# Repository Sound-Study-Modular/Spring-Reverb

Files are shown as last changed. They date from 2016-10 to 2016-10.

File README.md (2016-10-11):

# Spring-Reverb

The Spring Reverb is a flexible, easy-to-build voltage controlled DIY mono spring reverb module. Traditional guitar reverbs are tuned to the sound of the guitar and the amplifier it is played through. This circuit is different; designed to be relatively clean and high-fi, with a lot of bass response. It can also be abused and driven into (externally patched) feedback.

The circuit, plans and PCB/panel designs are open source and shared under Creative Commons.

- Works with a variety of spring reverb tanks, or with the Accutronics BTDR-2 reverb ‘brick’ designed by Brian Neunaber
- Includes PCB panel designs that can be very cheaply produced.
- Vactrol crossfade between dry and wet
- Tilt EQ on the reverb send to tune the voice of the reverb
- X-Fade input so the module can also be used as a standalone vactrol crossfader
- Attenuverter on the crossfade CV input
- Options for reverb tank connection and placement including front panel sockets.
- Optional (unbuffered) PCB connections for 100% wet and post-EQ dry outputs
- 6hp wide (NB: If using the brick, mounted horizontally, the brick extends 5mm over the PCB to the left of the module, around 25mm back from the front panel, so mount the reverb next to a shallow module)
- Around 60mm deep including a phono plug for the reverb tank coming from the back. Just 35mm deep if you mount the reverb connections on the front panel

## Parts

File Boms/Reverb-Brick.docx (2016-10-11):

Resistors:

QTY | Value | Ref. | Mouser Part #
1 | 22Ω | R4 | 291-22-RC
1 | 470Ω | R7b | 291-470-RC
1 | 1kΩ | R8 | 291-1k-RC
5 | 2.2kΩ | R3, R11, R12, R14, R23 | 291-2.2k-RC
1 | 4.7kΩ | R5 | 291-4.7k-RC
2 | 6.8kΩ | R13, R15 | 291-6.8k-RC
4 | 10kΩ | R18, R19, R20, R21 | 291-10k-RC
2 | 22kΩ | R6, R22 | 291-22k-RC
3 | 47kΩ | R16, R17, R7a | 291-47k-RC
1 | 68kΩ | R24 | 291-68k-RC
5 | 100kΩ | R1, R10, R31, R33, R34 | 291-100k-RC

TOTAL: 26

Diodes:

QTY | Value | Ref. | Mouser Part #
2 | 1N4002 | D3, D4 | 863-1N4002G
1 | 3mm Green LED | LED1 | 604-WP710A10GD

TOTAL: 3

Capacitors:

QTY | Value | Ref. | Mouser Part #
1 | 22pF Ceramic | C13 | 140-50N5-220J-RC
1 | 1nF Ceramic | C1 | 140-50P2-102K-RC
1 | 2.2nF Ceramic | C9 | 140-50Z5-222M-RC
1 | 10nF Ceramic | C3 | 594-D103Z25Z5VF63L6R
2 | 33nF Ceramic | C6, C7 | 594-K333K15X7RF5TL2
8 | 100nF Ceramic | C4, C5, C10, C11, C15, C16, C18, C19 | 140-50V5-104Z-RC
4 | 10uF Electrolytic | C2, C12, C14, C17 | 667-EEU-HD1H100
1 | 22uF Electrolytic | C8 | 140-SEA220M1VBK0607

TOTAL: 19

Integrated Circuits:

QTY | Value | Ref. | Mouser Part #
3 | TL072 | BRICK, IC4_DRV_RCVR, IC2_EQ | 595-TL072IPE4
1 | TL074 | IC1 | 595-TL074CN
3 | 8 Pin DIP Socket | BRICK, IC4_DRV_RCVR, IC2_EQ | 571-1-2199298-2
1 | 14 Pin DIP Socket | IC1 | 571-1-2199298-4

TOTAL: 8

Potentiometers:

QTY | Value | Ref. | Mouser Part #
2 | 10kΩ 9mm Vert Mount | R2, TILT_EQ | Synthrotek
2 | 50kΩ 9mm Vert Mount | ATTEN-U, BLEND | Synthrotek
4 | Nylon Potentiometer Spacers | See assembly Instructions | Synthrotek

TOTAL: 4

Transistors / Voltage Regulators:

QTY | Value | Ref. | Mouser Part #
1 | 2N3904 | T1 | 512-2N3904BU
1 | LM78L05 | 78L05 | 512-LM78L05ACZ

TOTAL: 2

Jacks / Headers:

QTY | Value | Ref. | Mouser Part #
1 | 2 Pin Jumper | JP1 *maybe | 571-8815451
1 | 1x3 Male Header | JP1 | 571-4-103321-5
1 | 1x5 Male Header | JP5 | 855-M20-9990546
1 | 1x5 Female Socket | JP3 | 517-929850-01-05-RA
1 | 2x5 Unshrouded Header | POWER | 649-68692-210HLF
4 | 3.5mm Vertical Mount Mono Jack | CV, OUT, X_FADE, IN | PJ301BM from Synthrotek, Various Suppliers

TOTAL: 9

Other:

QTY | Value | Ref. | Mouser Part #
2 | 200mA Resettable Fuse | | 652-MFR020-LF
1 | Vactrol / Optocoupler | LDR1 | Synthrotek
1 | Accutronics Reverb Brick | | BTDR-2H
2 | Hex Spacer | N/A | Synthrotek
6 | 2.5 x 6mm Screws | N/A | Synthrotek
2 | 3.0 x 6mm Screws | N/A | Synthrotek
3 | White Davies Clone Knobs | N/A | Synthrotek
1 | PCB/Panel Set | N/A | Synthrotek

TOTAL: 18

Spring Reverb - Accutronics Brick BOM Updated: 09.15.2016

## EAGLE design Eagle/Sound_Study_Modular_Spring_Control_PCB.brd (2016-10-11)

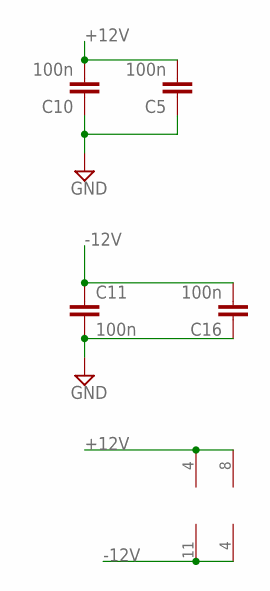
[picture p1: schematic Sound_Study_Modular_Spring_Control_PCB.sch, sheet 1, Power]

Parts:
C5, C10, C11, C16: 100n; C050-024X044
IC1: TL074; DIL14
IC2_EQ: NE5532; DIL08

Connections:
+12V: C5.2, C10.2, IC1.4 (V+), IC2_EQ.8 (V+); also elsewhere on the board
-12V: C11.1, C16.2, IC1.11 (V-), IC2_EQ.4 (V-); also elsewhere on the board
GND: C5.1, C10.1, C11.2, C16.1; also elsewhere on the board

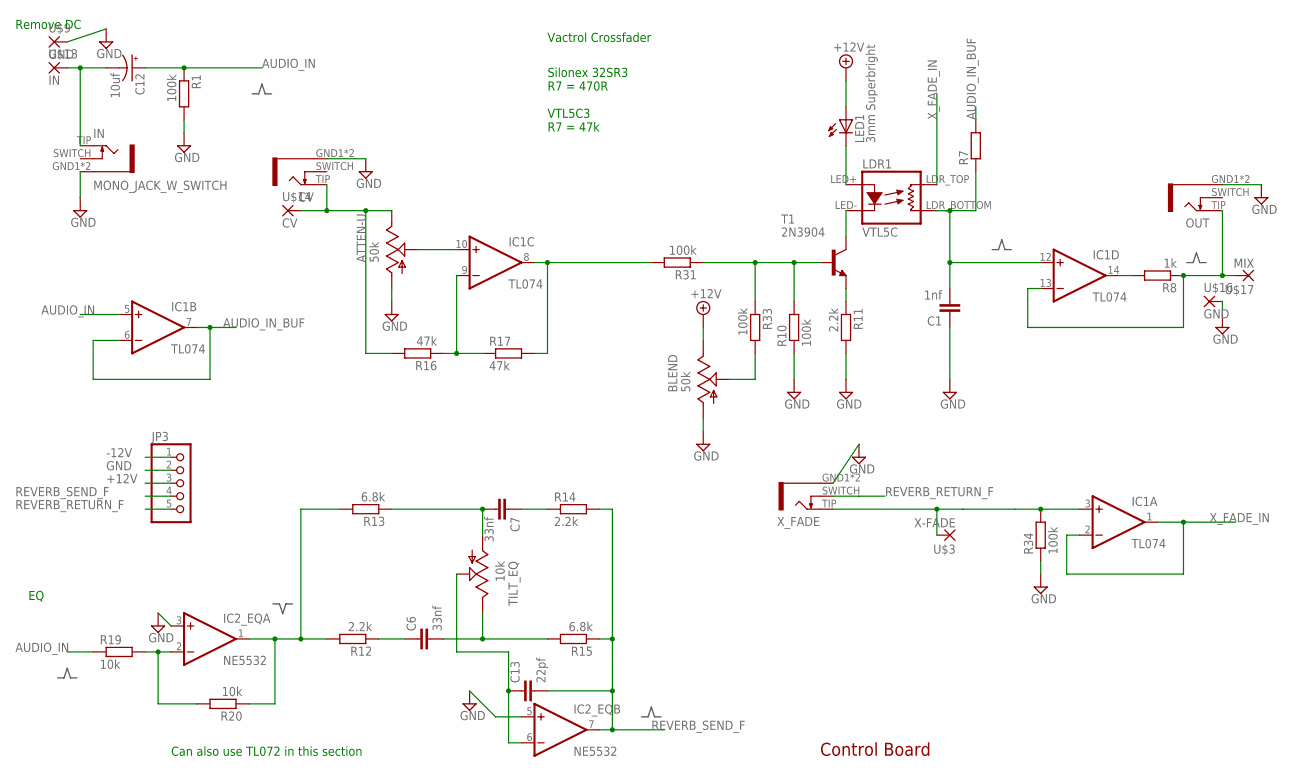
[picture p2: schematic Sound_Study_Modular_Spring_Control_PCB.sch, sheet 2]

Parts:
ATTEN-U: 50k; EVUF
BLEND: 50k; EVUF
C1: 1nf; C050-024X044
C6, C7: 33nf; C050-024X044
C12: 10uf; 050_020
C13: 22pf; 050X030_025
CV: MONO_JACK_W_SWITCH; ERTHENVAR
IC1: TL074; DIL14
IC2_EQ: NE5532; DIL08
IN: MONO_JACK_W_SWITCH; ERTHENVAR
JP3: PINHD-1X5; 1X05
LDR1: VTL5C; VACTROL_COMPACT
LED1: 3mm Superbright; LED3MM
OUT: MONO_JACK_W_SWITCH; ERTHENVAR
R1: 100k; VERT-RESISTOR
R7: R-EU_STANDARD_RESISTOR; 0207/10
R8: 1k; 0207/10
R10, R31, R33, R34: 100k; 0207/10
R11, R12, R14: 2.2k; 0207/10
R13, R15: 6.8k; 0207/10
R16, R17: 47k; VERT-RESISTOR
R19: 10k; VERT-RESISTOR
R20: 10k; 0207/10
T1: 2N3904; TO92
TILT_EQ: 10k; EVUF
U$3: X-FADE; LONG_PAD_1
U$9, U$16: GND; LONG_PAD_1
U$13: IN; LONG_PAD_1
U$14: CV; LONG_PAD_1
U$17: MIX; LONG_PAD_1
X_FADE: MONO_JACK_W_SWITCH; ERTHENVAR

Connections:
+12V: BLEND.3 (E), JP3.3, LED1.A; also elsewhere on the board
-12V: JP3.1; also elsewhere on the board
AUDIO_IN: C12.+, IC1.5 (+IN), R1.1, R19.1
AUDIO_IN_BUF: IC1.6 (-IN), IC1.7 (OUT), R7.2
GND: ATTEN-U.1 (A), BLEND.1 (A), C1.1, CV.GND1 (SLEEVE), CV.GND2 (SLEEVE), IC2_EQ.3 (+IN), IC2_EQ.5 (+IN), IN.GND1 (SLEEVE), IN.GND2 (SLEEVE), JP3.2, OUT.GND1 (SLEEVE), OUT.GND2 (SLEEVE), R1.2, R10.1, R11.2, R34.1, U$9.P$1, U$16.P$1, X_FADE.GND1 (SLEEVE), X_FADE.GND2 (SLEEVE); also elsewhere on the board
MIX_OUT_B: IC1.13 (-IN), OUT.TIP, R8.1, U$17.P$1
unnamed: C12.-, IN.TIP, U$13.P$1
unnamed: IC1.3 (+IN), R34.2, U$3.P$1, X_FADE.TIP
unnamed: ATTEN-U.3 (E), CV.TIP, R16.2, U$14.P$1
unnamed: C6.1, R12.1
unnamed: BLEND.2 (S), R33.2
unnamed: IC1.14 (OUT), R8.2
unnamed: C6.2, R15.2, TILT_EQ.3 (E)
unnamed: R11.1, T1.3 (E)
unnamed: C7.2, R13.1, TILT_EQ.1 (A)
unnamed: ATTEN-U.2 (S), IC1.10 (+IN)
unnamed: C7.1, R14.1
unnamed: C13.1, IC2_EQ.6 (-IN), TILT_EQ.2 (S)
unnamed: IC1.9 (-IN), R16.1, R17.1
unnamed: IC2_EQ.2 (-IN), R19.2, R20.2
unnamed: IC1.8 (OUT), R17.2, R31.2
unnamed: LDR1.LED+, LED1.K (C)
unnamed: IC2_EQ.1 (OUT), R12.2, R13.2, R20.1
unnamed: R10.2, R31.1, R33.1, T1.2 (B)
unnamed: LDR1.LED-, T1.1 (C)
REVERB_RETURN_F: JP3.5, X_FADE.SWITCH
REVERB_SEND_F: C13.2, IC2_EQ.7 (OUT), JP3.4, R14.2, R15.1
SUM: C1.2, IC1.12 (+IN), LDR1.LDR_BOTTOM (RES2), R7.1
X_FADE_IN: IC1.1 (OUT), IC1.2 (-IN), LDR1.LDR_TOP (RES1)

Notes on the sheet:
Control Board
Vactrol Crossfader
Silonex 32SR3 R7 = 470R VTL5C3 R7 = 47k
Remove DC
Can also use TL072 in this section

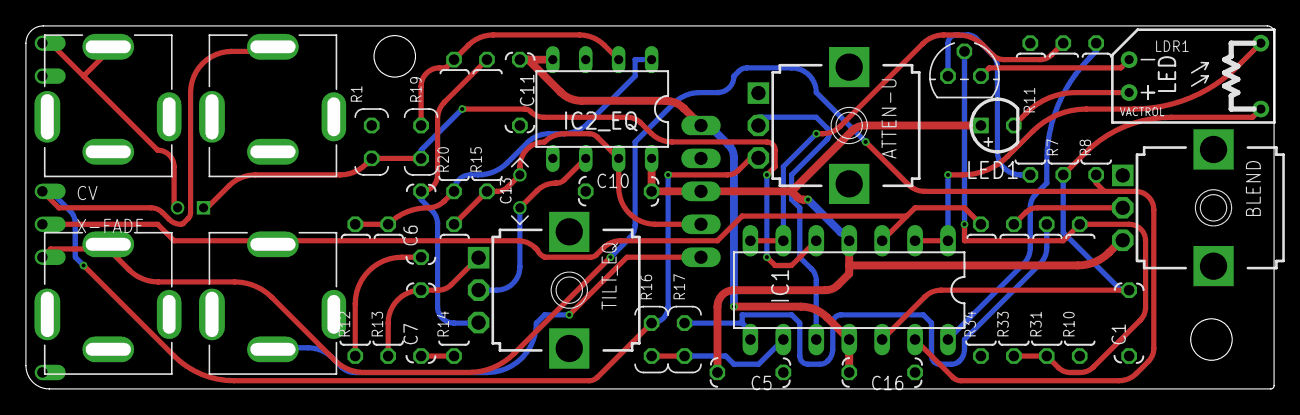
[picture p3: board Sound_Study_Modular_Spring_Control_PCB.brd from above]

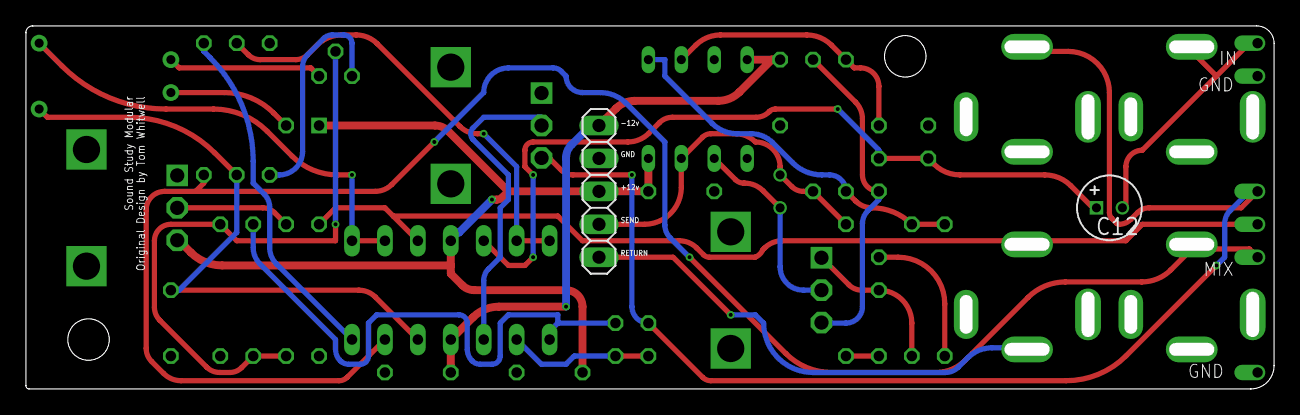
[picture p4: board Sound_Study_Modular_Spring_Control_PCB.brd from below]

Board: 4 copper layers, 96.3 x 28.0 mm, 44 parts (2 on the bottom side), 29 nets.

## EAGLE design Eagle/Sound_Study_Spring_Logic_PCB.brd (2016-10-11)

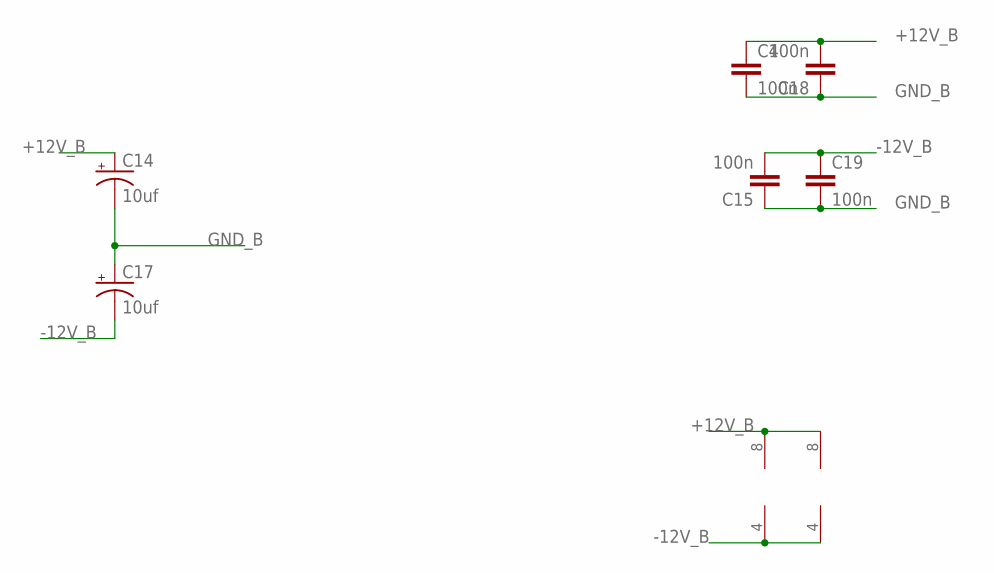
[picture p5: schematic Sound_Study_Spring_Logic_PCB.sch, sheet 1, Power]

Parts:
BRICK: TL072; DIL08
C4, C15, C18, C19: 100n; C050-024X044
C14, C17: 10uf; CPOL-RADIAL-10UF-25V
IC4_DRV_RCVR: TL072; DIL08

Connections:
+12V_B: BRICK.8 (V+), C4.1, C14.1 (+), C18.2, IC4_DRV_RCVR.8 (V+); also elsewhere on the board
-12V_B: BRICK.4 (V-), C15.2, C17.2 (-), C19.1, IC4_DRV_RCVR.4 (V-); also elsewhere on the board
GND_B: C4.2, C14.2 (-), C15.1, C17.1 (+), C18.1, C19.2; also elsewhere on the board

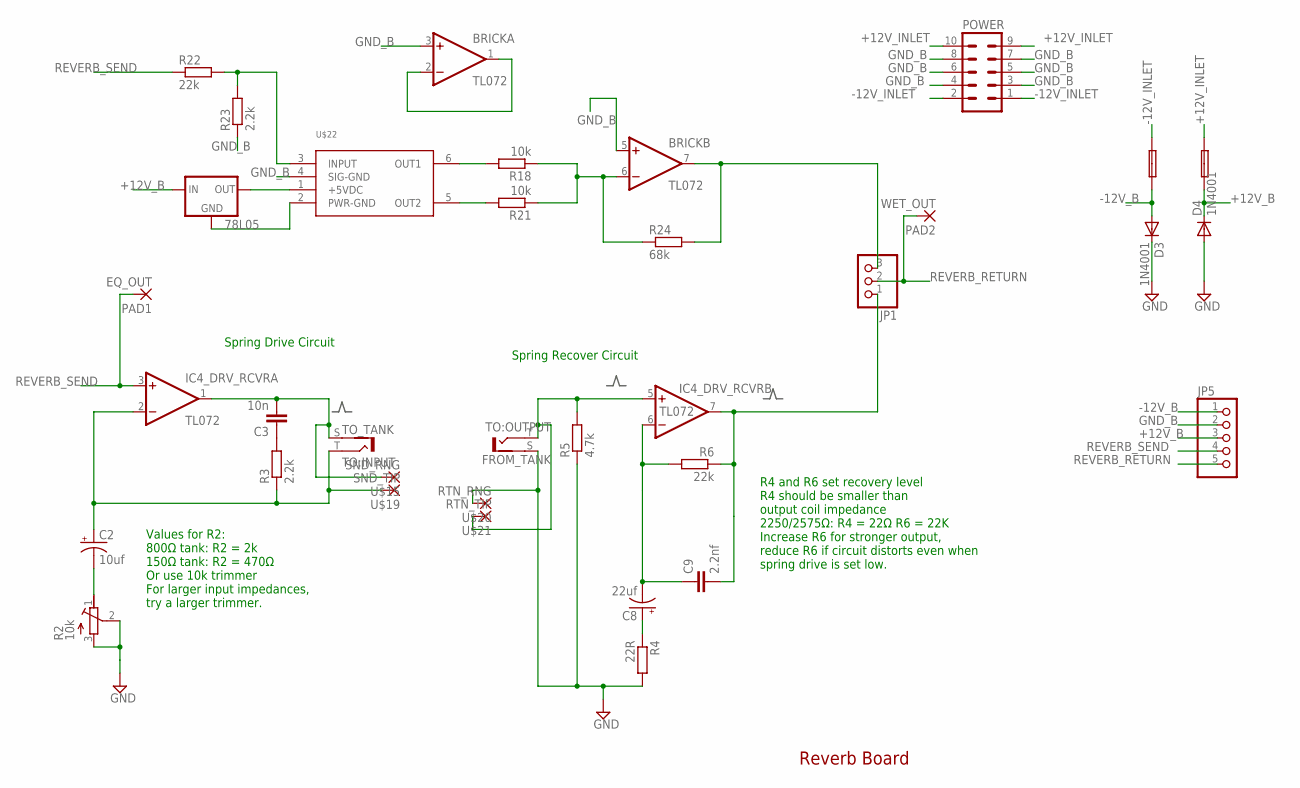
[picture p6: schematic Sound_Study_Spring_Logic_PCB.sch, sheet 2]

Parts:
0.1A_FUSE, 0.1A_FUSE_2: FUSE; C050H075X075
78L05: V_REG_78XXTO-92; TO-92
BRICK: TL072; DIL08
C2: 10uf; CPOL-RADIAL-10UF-25V
C3: 10n; C050-024X044
C8: 22uf; CPOL-RADIAL-10UF-25V
C9: 2.2nf; C050-024X044
D3, D4: 1N4001; DO41-10
IC4_DRV_RCVR: TL072; DIL08
JP1: PINHD-1X3; 1X03
JP5: PINHD-1X5; 1X05
PAD1: EQ_OUT; LONG_PAD_1
PAD2: WET_OUT; LONG_PAD_1
POWER: 10_PIN_HEADER; MA05-2
R2: 10k; RTRIMT93YA
R3, R23: 2.2k; 0207/10
R4: 22R; 0207/10
R5: 4.7k; 0207/10
R6, R22: 22k; 0207/10
R18, R21: 10k; 0207/10
R24: 68k; 0207/10
TO:INPUT: TO_TANK; BTOR1
TO:OUTPUT: FROM_TANK; BTOR1
U$15: SND_RNG; LONG_PAD_1
U$19: SND_TIP; LONG_PAD_1
U$20: RTN_RNG; LONG_PAD_1
U$21: RTN_TIP; LONG_PAD_1
U$22: BTDR-2H

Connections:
+12V_B: 0.1A_FUSE_2.1, 78L05.3 (IN), D4.C, JP5.3; also elsewhere on the board
+12V_INLET: 0.1A_FUSE_2.2, POWER.9, POWER.10
-12V_B: 0.1A_FUSE.1, D3.A, JP5.1; also elsewhere on the board
-12V_INLET: 0.1A_FUSE.2, POWER.1, POWER.2
GND_B: BRICK.3 (+IN), BRICK.5 (+IN), D3.C, D4.A, JP5.2, POWER.3, POWER.4, POWER.5, POWER.6, POWER.7, POWER.8, R2.2 (S), R2.3 (E), R4.2, R5.1, R23.1, TO:OUTPUT.S (2), U$20.P$1, U$22.4 (SIG-GND); also elsewhere on the board
unnamed: C2.2 (-), R2.1 (A)
unnamed: C3.1, R3.2
unnamed: C3.2, IC4_DRV_RCVR.1 (OUT), TO:INPUT.S (2), U$15.P$1
unnamed: C2.1 (+), IC4_DRV_RCVR.2 (-IN), R3.1, TO:INPUT.T (1), U$19.P$1
unnamed: IC4_DRV_RCVR.5 (+IN), R5.2, TO:OUTPUT.T (1), U$21.P$1
unnamed: C8.1 (+), R4.1
unnamed: C8.2 (-), C9.1, IC4_DRV_RCVR.6 (-IN), R6.2
unnamed: 78L05.1 (OUT), U$22.1 (+5VDC)
unnamed: R22.2, R23.2, U$22.3 (INPUT)
unnamed: R18.2, U$22.6 (OUT1)
unnamed: R21.2, U$22.5 (OUT2)
unnamed: BRICK.6 (-IN), R18.1, R21.1, R24.1
unnamed: 78L05.2 (GND), U$22.2 (PWR-GND)
unnamed: BRICK.1 (OUT), BRICK.2 (-IN)
unnamed: BRICK.7 (OUT), JP1.3, R24.2
unnamed: C9.2, IC4_DRV_RCVR.7 (OUT), JP1.1, R6.1
REVERB_RETURN: JP1.2, JP5.5, PAD2.P$1
REVERB_SEND: IC4_DRV_RCVR.3 (+IN), JP5.4, PAD1.P$1, R22.1

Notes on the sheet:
Values for R2: 800Ω tank: R2 = 2k 150Ω tank: R2 = 470Ω Or use 10k trimmer For larger input impedances, try a larger trimmer.
Spring Drive Circuit
R4 and R6 set recovery level R4 should be smaller than output coil impedance 2250/2575Ω: R4 = 22Ω R6 = 22K Increase R6 for stronger output, reduce R6 if circuit distorts even when spring drive is set low.
Spring Recover Circuit
Reverb Board

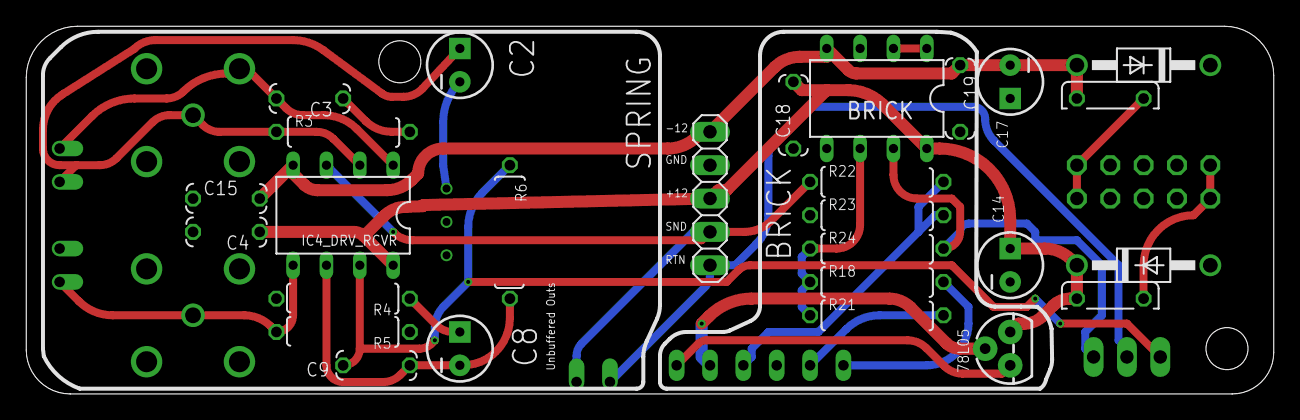
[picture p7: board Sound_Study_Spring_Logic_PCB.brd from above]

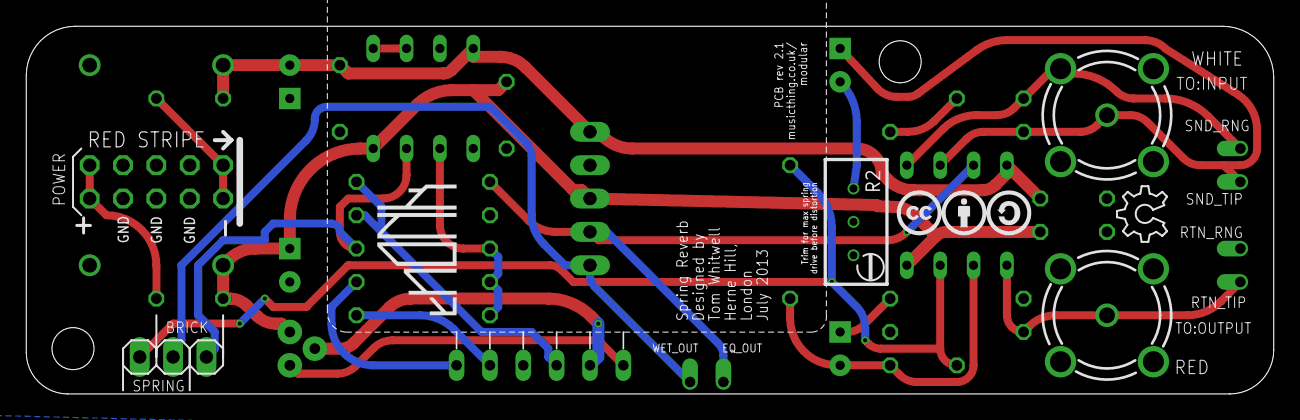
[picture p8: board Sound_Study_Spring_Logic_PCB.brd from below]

Board: 4 copper layers, 95.0 x 28.0 mm, 43 parts (10 on the bottom side), 23 nets.

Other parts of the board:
U$1: CC_1CM_SCREENPRINT
U$2: MTM_1CM_KEEPOUT
U$3: OSHW_6X150_NOTEXT
U$4: THONK_1CM_SCREENPRINT

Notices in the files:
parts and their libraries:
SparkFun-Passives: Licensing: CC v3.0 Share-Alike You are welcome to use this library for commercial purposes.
